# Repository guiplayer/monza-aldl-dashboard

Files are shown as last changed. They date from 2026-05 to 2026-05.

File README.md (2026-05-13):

# Monza ALDL Dashboard

Dashboard embarcado para Chevrolet Monza EFI com comunicação ALDL, display TFT ST7789, sensores auxiliares, logs em cartão SD, upload OTA e mascote animado.

O projeto foi desenvolvido para monitorar dados da ECU Multec 700 via ALDL 8192 baud, exibindo informações em tempo real no display TFT e permitindo diagnósticos, configuração, logs e animações diretamente no ESP32.

---

## 🚗 Veículo alvo

- Chevrolet Monza 1996
- Motor 2.0 EFI gasolina
- ECU Multec 700
- Comunicação ALDL 8192 baud
- Linha ALDL no pino M do conector de diagnóstico

---

## ✨ Principais recursos

- Comunicação ALDL com ECU Multec 700
- Dashboards com dados em tempo real
- Telas individuais de sensores
- Diagnóstico ALDL
- Leitura de códigos de falha da ECU
- Comando para limpar erros da ECU
- Status de SD, I2C, BME280, MPU6050 e alimentação
- Configuração de brilho
- Configuração de buzzer
- Configuração de alertas
- Dashboard inicial configurável
- Upload OTA de firmware via modo AP
- Upload de GIFs via navegador
- GIF de abertura configurável
- Redimensionamento automático de GIFs maiores que a tela
- Logs em CSV no cartão SD
- Limpeza automática de logs antigos
- Tela G-Force usando MPU6050
- Mascote / Monzagotchi com humor baseado nos dados do carro

---

## 🖼️ Galeria do projeto

Imagens reais do painel, dashboards e montagem do projeto.

### Dashboard / interface

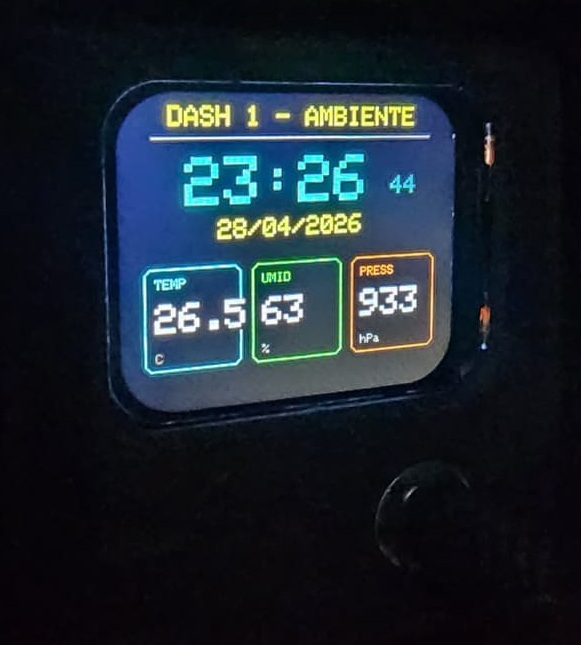
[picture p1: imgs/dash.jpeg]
Dashboard principal


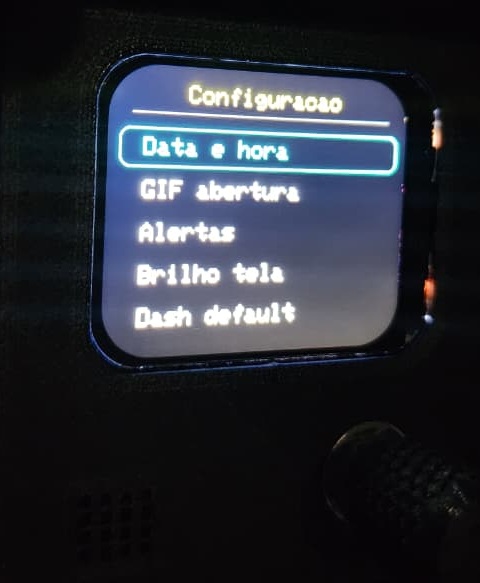
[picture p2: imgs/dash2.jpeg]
Dashboard 2


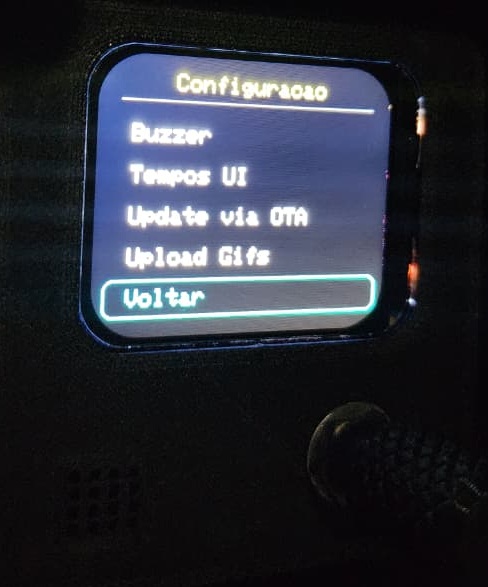
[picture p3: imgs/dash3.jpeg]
Dashboard 3


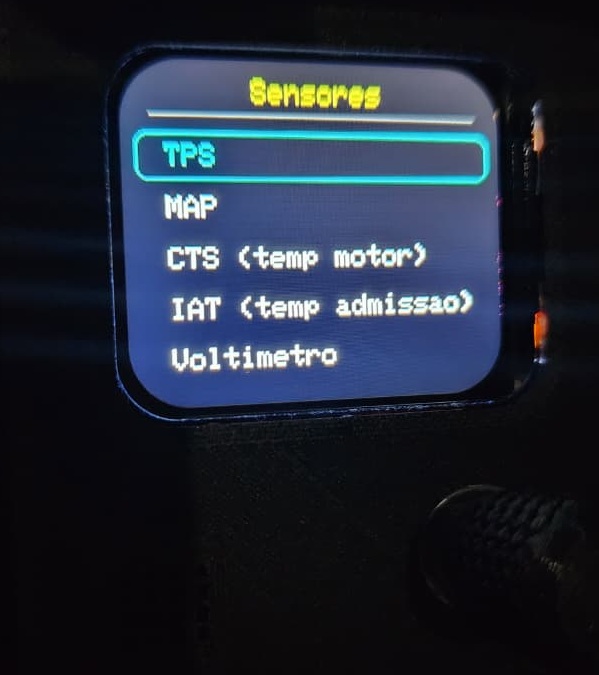
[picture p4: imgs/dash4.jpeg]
Dashboard 4


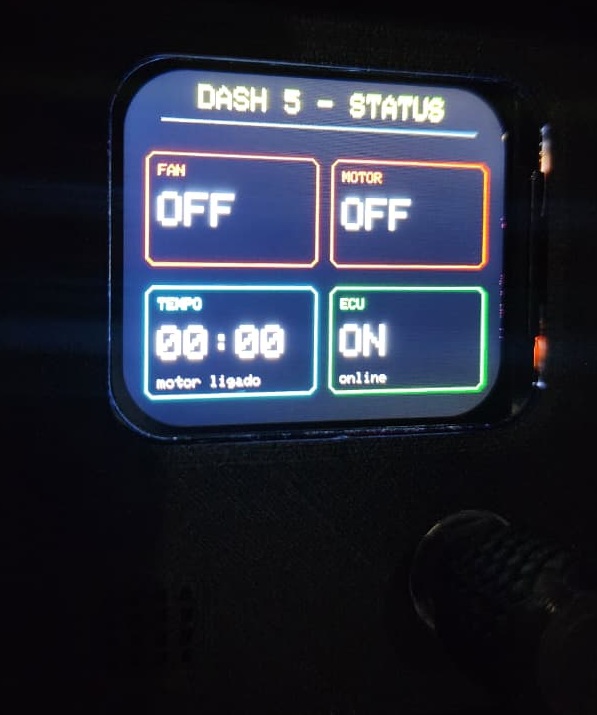
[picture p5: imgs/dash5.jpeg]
Dashboard 5


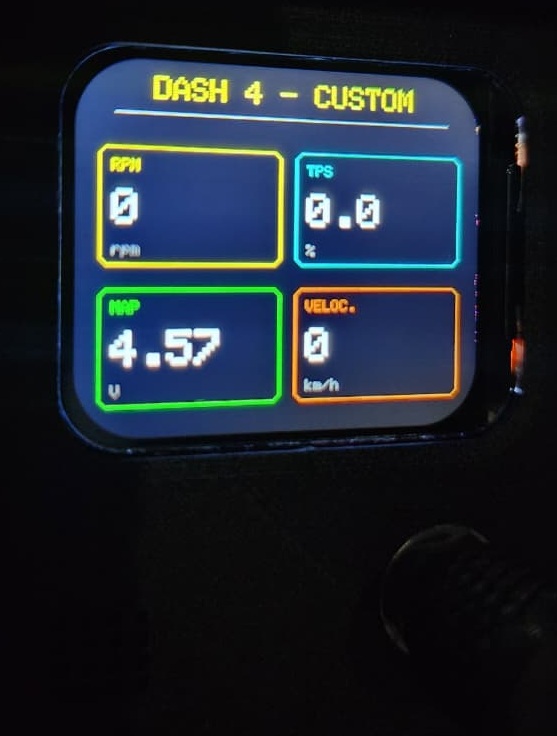
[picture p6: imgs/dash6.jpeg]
Dashboard 6


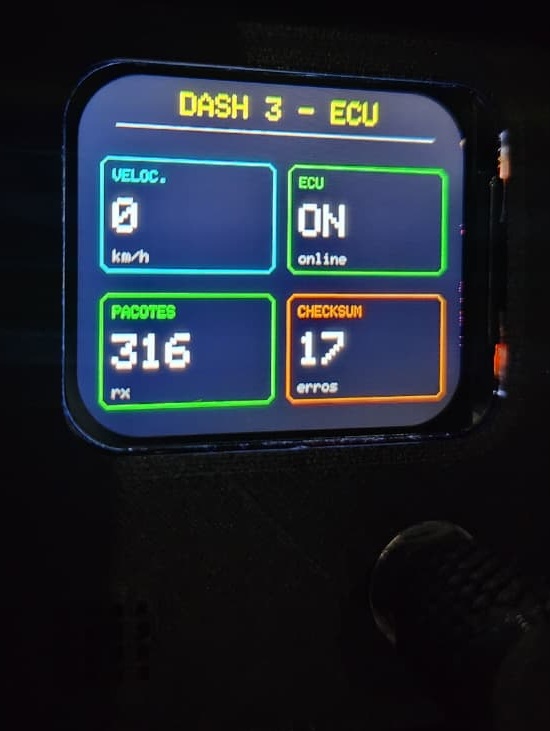
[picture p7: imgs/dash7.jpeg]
Dashboard 7


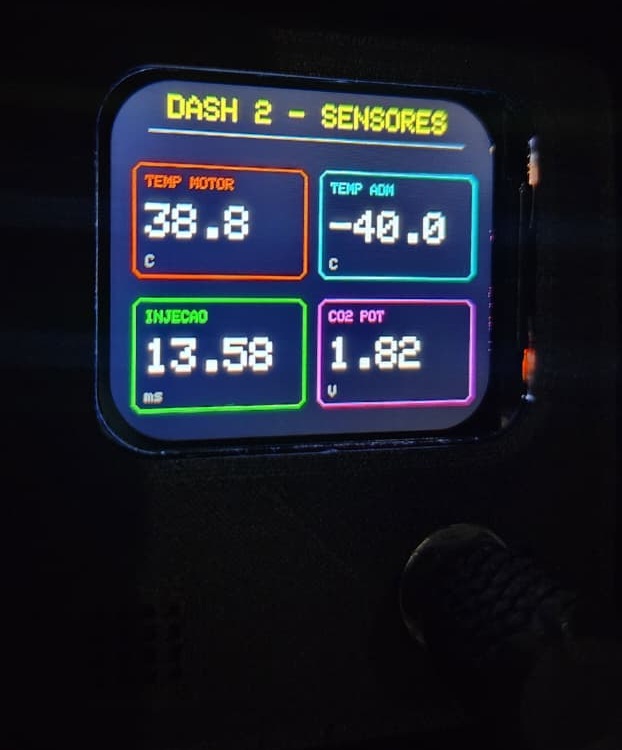
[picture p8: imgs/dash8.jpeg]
Dashboard 8


### GIFs usados no projeto

Os GIFs utilizados no projeto ficam na pasta:

```txt
/gifs/
```

Arquivos adicionados no repositório:

```txt
gifs/abertura.gif
gifs/camera.gif
```

Exemplo de uso:

- `abertura.gif`: GIF de abertura do painel
- `camera.gif`: GIF adicional para testes/animações

### Vídeo de exemplo

Um vídeo demonstrativo também foi adicionado na pasta `imgs`:

```txt
imgs/example.mp4
```

> O vídeo pode ser usado para demonstrar o painel funcionando, menus, dashboards ou animações.

---

## 🧱 Arquivos 3D para impressão

O repositório também possui arquivos STL para impressão 3D da caixa e da frente do projeto.

Arquivos adicionados:

```txt
stl/ALDLMonza_BOX.STL
stl/ALDLMonza_Front.STL
```

### Peças

| Arquivo | Descrição |
|---|---|
| `ALDLMonza_BOX.STL` | Caixa/base do projeto |
| `ALDLMonza_Front.STL` | Frente/moldura do display |

Essas peças podem ser impressas em 3D para montar o painel físico com o ESP32, display ST7789, encoder e demais módulos.

### Sugestões de impressão

- Material: PLA, PETG ou ABS
- Altura de camada: 0.16 mm a 0.28 mm
- Infill: 20% a 40% para uso normal
- Infill maior pode ser usado em suportes ou regiões que precisem de mais resistência
- Conferir a orientação da peça no fatiador antes de imprimir
- Verificar folgas do display, encoder e conectores antes da montagem final

---

## 📁 Estrutura de arquivos de mídia e impressão

Arquivos de mídia e modelos 3D disponíveis no repositório:

```txt
/
├── gifs/
│   ├── abertura.gif
│   └── camera.gif
├── imgs/
│   ├── dash.jpeg
│   ├── dash2.jpeg
│   ├── dash3.jpeg
│   ├── dash4.jpeg
│   ├── dash5.jpeg
│   ├── dash6.jpeg
│   ├── dash7.jpeg
│   ├── dash8.jpeg
│   └── example.mp4
└── stl/
    ├── ALDLMonza_BOX.STL
    └── ALDLMonza_Front.STL
```

---

## 🖥️ Display

O projeto usa um display TFT ST7789 SPI.

Configuração atual:

- Display ST7789
- Resolução usada no projeto: 280 x 240
- Biblioteca: Adafruit ST7789 / Adafruit GFX
- Backlight controlado pelo GPIO 32

---

## 📊 Dashboards

O sistema possui múltiplos dashboards acessíveis pelo menu principal.

### Dashboards atuais

1. **Relógio**
   - Hora
   - Data
   - Temperatura ambiente
   - Umidade
   - Pressão atmosférica

2. **Módulo**
   - ECU ID em hexadecimal
   - ECU ID em decimal
   - Código do módulo
   - Código GM

3. **Motor**
   - RPM
   - TPS
   - MAP
   - Temperatura do motor

4. **Motor 2**
   - Tensão da bateria
   - Velocidade
   - IAC Steps
   - Potenciômetro CO2

5. **Motor 3**
   - RPM
   - TPS
   - MAP
   - Velocidade

6. **Mistura**
   - Avanço de ignição / SPK
   - AFR desejado pela ECU
   - Tempo de injeção
   - Potenciômetro CO2

7. **Status**
   - FAN estimado
   - VMOTOR
   - Tempo de motor ligado
   - Temperatura de admissão

8. **Status ECU**
   - ECU online/offline
   - Pacotes recebidos
   - Erros de checksum
   - Bytes descartados

9. **G-Force**
   - Força lateral
   - Força longitudinal
   - Força vertical
   - G total

---

## 🧪 Sensores e dados ALDL

O projeto lê e exibe diversos dados vindos da ECU via ALDL.

### Telas individuais de sensores

- RPM
- TPS
- MAP
- CTS / temperatura do motor
- IAT / temperatura de admissão
- VBAT / tensão da bateria
- Velocidade
- IAC Steps
- Tempo de injeção
- Potenciômetro CO2
- SPK / avanço de ignição
- AFR desejado pela ECU
- FAN estimado
- VMOTOR
- Tempo de motor ligado

---

## ⚠️ Alertas

O sistema possui alertas configuráveis para:

- Temperatura alta do motor
- Tensão baixa da bateria
- Shift Light por RPM

Quando um alerta é acionado, uma tela de aviso é exibida.

Na tela do mascote, os alertas são representados pelo próprio humor do Monzagotchi.

---

## 🐾 Mascote / Monzagotchi

O projeto possui uma tela de mascote inspirada em Tamagotchi, chamada **Monzagotchi**.

O mascote fica no menu principal, junto com Dashboard, Sensores, Diagnóstico e Configuração.

Menu principal:

```txt
Dashboard
Sensores
Diagnostico
Mascote
Configuracao
```

A tela do mascote também ativa a comunicação ALDL por trás, para que ele reaja aos dados reais do carro.

### Estados do mascote

| Estado | Condição |
|---|---|
| Dormindo | Sem frame válido da ECU / aguardando comunicação |
| Feliz | Dados normais |
| Andando | Velocidade maior que 0 |
| Assustado | RPM acima do limite do Shift Light |
| Triste | ECU offline |
| Doente | Tensão baixa da bateria |
| Quente | Temperatura do motor acima do limite de alerta |

### Frases do mascote

Exemplos de falas usadas na tela:

- `ZzZ... esperando a ECU`
- `Tudo certo no Monza!`
- `Vrum vrum!`
- `EITA RPM!`
- `Cade a ECU?`
- `Bateria fraca :(`
- `To fritando!`

### GIFs do mascote

Os GIFs do mascote ficam na pasta:

```txt
/mascote/
```

Arquivos esperados:

```txt
/mascote/dormindo.gif
/mascote/feliz.gif
/mascote/andando.gif
/mascote/assustado.gif
/mascote/triste.gif
/mascote/doente.gif
/mascote/quente.gif
```

Se algum GIF ainda não foi enviado, a tela mostra um placeholder com o estado atual.

### Upload dos GIFs do mascote

Os GIFs podem ser enviados pelo próprio dashboard usando a tela:

```txt
Configuracao > Upload Gifs
```

O ESP32 cria uma rede Wi-Fi em modo AP. Depois basta acessar o IP informado na tela, normalmente:

```txt
192.168.4.1
```

Na página de upload existe uma área separada para enviar/substituir os GIFs de cada humor do mascote.

---

## 💾 Logs no cartão SD

O projeto possui gravação de logs em CSV no cartão SD.

Os logs são gravados somente quando:

- A opção de logs está ativada
- A tela atual usa dados ALDL
- A ECU está conectada
- Existe frame válido recebido
- O intervalo configurado foi atingido

Os arquivos são salvos na pasta:

```txt
/logs/
```

Formato do nome:

```txt
/logs/aldl_YYYYMMDD_HHMMSS.csv
```

Exemplo:

```txt
/logs/aldl_20260512_213410.csv
```

### Sensores disponíveis para log

É possível escolher quais dados serão gravados:

- RPM
- TPS
- MAP
- CTS / temperatura do motor
- VBAT / tensão da bateria
- Velocidade
- IAC Steps
- Tempo de injeção
- CO2 POT
- SPK / avanço de ignição
- AFR desejado
- FAN estimado
- VMOTOR
- Tempo de motor ligado

### Exemplo de CSV

```csv
millis,data,hora,rpm,tps_percent,map_v,cts_c,vbat_v,velocidade_kmh,iac_steps,injecao_ms,co2_v,spk_graus,afr_desejado,fan,vmotor,tempo_motor_s
123456,12/05/2026,21:34:10,920,0.4,1.28,87.5,13.8,0,34,2.15,1.82,12.3,14.7,OFF,ON,754
```

### Limpeza automática

Quando o cartão SD passa de aproximadamente **90% de uso**, o sistema começa a apagar os logs mais antigos até reduzir o uso para aproximadamente **80%**.

Isso evita que o cartão fique cheio durante o uso.

---

## 📡 Upload OTA

O projeto possui uma tela de atualização OTA via modo AP.

Caminho:

```txt
Configuracao > Update via OTA
```

O ESP32 cria uma rede Wi-Fi própria e permite enviar o firmware pelo navegador.

SSID padrão:

```txt
MonzaDash-OTA
```

Senha padrão:

```txt
12345678
```

IP padrão:

```txt
192.168.4.1
```

---

## 🖼️ Upload de GIFs

O projeto permite enviar GIFs para o cartão SD pelo navegador.

Caminho:

```txt
Configuracao > Upload Gifs
```

A tela de upload permite:

- Enviar GIF de abertura
- Listar GIFs no SD
- Visualizar prévia dos GIFs
- Ver dimensão dos GIFs
- Renomear GIFs
- Deletar GIFs
- Enviar/substituir GIFs do mascote por humor

---

## 🧩 Hardware utilizado

### 🖥️ Display TFT ST7789

Display TFT ST7789 SPI, 8 pinos.

| Display TFT | ESP32 |
|---|---|
| VCC | 3.3V |
| GND | GND |
| SCL | GPIO 18 / SPI Clock |
| SDA | GPIO 23 / SPI MOSI |
| RES | GPIO 4 |
| DC | GPIO 2 |
| CS | GPIO 5 |
| BLK | GPIO 32 ou 3.3V direto |

---

### 🔊 Buzzer passivo

| Buzzer | ESP32 |
|---|---|
| + | GPIO 33 |
| - | GND |

---

### ⏰ RTC DS3231

| DS3231 | ESP32 |
|---|---|
| SDA | GPIO 21 |
| SCL | GPIO 22 |
| VCC | 5V |
| GND | GND |

---

### 🌡️ BME280

| BME280 | ESP32 |
|---|---|
| SDA | GPIO 21 |
| SCL | GPIO 22 |
| VCC | 3.3V |
| GND | GND |

---

### 🧭 GY-521 / MPU6050

| GY-521 / MPU6050 | ESP32 |
|---|---|
| SDA | GPIO 21 |
| SCL | GPIO 22 |
| VCC | 3.3V |
| GND | GND |

---

### 💾 MicroSD

| MicroSD | ESP32 |
|---|---|
| CLK / SCK | GPIO 18 |
| MOSI | GPIO 23 |
| MISO | GPIO 19 |
| CS | GPIO 13 |
| VCC | 3.3V |
| GND | GND |

---

### 🔘 Encoder KY-040

| KY-040 | ESP32 |
|---|---|
| CLK | GPIO 25 |
| DT | GPIO 26 |
| SW | GPIO 27 |
| VCC | 3.3V |
| GND | GND |

---

## 🚗 Ligações com o carro

| Sinal do carro | ESP32 / circuito |
|---|---|
| 5V pós-regulador | VIN do ESP32 |
| GND | GND do ESP32 |
| Iluminação 12V | GPIO 34 |
| ALDL RX | GPIO 16 |
| ALDL TX | GPIO 17 |

> Observação: a linha ALDL do carro não deve ser ligada diretamente ao ESP32 sem o circuito de interface/proteção usado no projeto.

---

## 🔋 Alimentação

A alimentação do projeto é feita a partir dos 12V do carro usando um conversor buck LM2596.

```txt
12V do carro -> LM2596
Saída 5V LM2596 -> VIN do ESP32
Saída 5V LM2596 -> DS3231
3.3V do ESP32 -> Display, BME280, MPU6050, MicroSD e Encoder
GND comum para todos os módulos
```

### Filtro contra ruído no LM2596

Para reduzir ruídos/interferências na alimentação e melhorar a estabilidade da leitura ALDL, foram adicionados capacitores no circuito do LM2596.

Capacitores utilizados:

| Capacitor | Posição sugerida | Função |
|---|---|---|
| 470µF / 25V eletrolítico | Entrada 12V do LM2596 | Ajuda a absorver quedas e oscilações da alimentação do carro |
| 10µF / 16V eletrolítico | Saída 5V do LM2596 | Ajuda a suavizar a saída de 5V |
| 100nF cerâmico | Próximo ao ESP32 e/ou sensores | Ajuda a filtrar ruído de alta frequência |
| 100nF cerâmico | Próximo ao módulo MicroSD | Ajuda na estabilidade durante leitura/gravação no SD |

Ligação recomendada:

```txt
12V carro  ----+---- LM2596 IN+
               |
             470µF
               |
GND carro  ----+---- LM2596 IN-

LM2596 OUT+ ----+---- VIN ESP32
                |
              10µF
                |
GND comum  -----+---- GND ESP32
```

Também é recomendado manter o GND comum entre:

- ESP32
- LM2596
- Display
- Sensores
- MicroSD
- RTC
- Circuito de interface ALDL

---

## 🔌 Barramento I2C

O projeto compartilha o mesmo barramento I2C entre:

- DS3231
- BME280
- MPU6050

Pinos usados:

```txt
SDA -> GPIO 21
SCL -> GPIO 22
```

Endereços comuns:

```txt
DS3231  -> 0x68
BME280  -> 0x76
MPU6050 -> 0x69
```

---

## 🧠 ALDL

Configuração da comunicação:

```txt
Baud rate: 8192
RX: GPIO 16
TX: GPIO 17
```

Comandos usados:

```txt
Shutup request:
F4 56 08 AE

Data stream request:
F4 57 01 00 B4

Clear DTC request:
F4 57 0A 00 AB
```

Frame esperado:

```txt
Header: F4 95 01
Payload: 63 bytes
Checksum: 1 byte
Total: 67 bytes
```

---

## 🧯 Códigos de falha monitorados

A tela de códigos ECU monitora falhas baseadas nos bytes de malfunction word.

Exemplos:

- Erro 12 - Sem pulsos de referência
- Erro 14 - Sensor de temperatura / curto massa
- Erro 15 - Sensor de temperatura / chicote
- Erro 21 - TPS voltagem alta
- Erro 22 - TPS voltagem baixa
- Erro 24 - Sem sinal sensor velocidade
- Erro 32 - Falha sistema EGR
- Erro 33 - MAP sinal alto
- Erro 34 - MAP sinal baixo
- Erro 35 - Atuador IAC
- Erro 42 - Módulo HEI
- Erro 51 - Unidade comando / MEM-CAL
- Erro 54 - Potenciômetro CO2
- Erro 55 - Unidade comando defeito

---

## ⚙️ Configurações salvas no SD

As configurações são salvas no arquivo:

```txt
/config.json
```

Exemplos de dados salvos:

- Brilho dia
- Brilho noite
- GIF de abertura
- Frequências do buzzer
- Modo do buzzer
- Polling ALDL
- Dashboard inicial
- Alertas
- Intervalos de atualização da UI
- Logs SD
- Sensores selecionados para log

---

## 📁 Estrutura sugerida do cartão SD

Estrutura usada no cartão SD instalado no painel:

```txt
/
├── config.json
├── abertura.gif
├── logs/
│   ├── aldl_20260512_213410.csv
│   └── aldl_20260512_214020.csv
└── mascote/
    ├── dormindo.gif
    ├── feliz.gif
    ├── andando.gif
    ├── assustado.gif
    ├── triste.gif
    ├── doente.gif
    └── quente.gif
```

Estrutura dos arquivos versionados no GitHub:

```txt
/
├── gifs/
│   ├── abertura.gif
│   └── camera.gif
├── imgs/
│   ├── dash.jpeg
│   ├── dash2.jpeg
│   ├── dash3.jpeg
│   ├── dash4.jpeg
│   ├── dash5.jpeg
│   ├── dash6.jpeg
│   ├── dash7.jpeg
│   ├── dash8.jpeg
│   └── example.mp4
└── stl/
    ├── ALDLMonza_BOX.STL
    └── ALDLMonza_Front.STL
```

---

## 🛠️ Bibliotecas usadas

- Wire
- SPI
- SD
- ArduinoJson
- AnimatedGIF
- Adafruit GFX
- Adafruit ST7789
- Adafruit BME280
- Adafruit MPU6050
- Adafruit Sensor
- RTClib
- WiFi
- WebServer
- Update
- vector

---

## 📌 Observações importantes

- A linha ALDL precisa de circuito de interface/proteção.
- O ESP32 trabalha em 3.3V.
- Não ligar sinais automotivos de 12V diretamente no ESP32.
- Usar GND comum entre todos os módulos.
- O cartão SD deve estar formatado corretamente.
- GIFs muito grandes podem afetar desempenho.
- Para melhor desempenho, prefira GIFs pequenos e próximos da resolução usada na tela.
- O AFR exibido é o AFR desejado/calculado pela ECU, não leitura real de wideband.
- No Monza EFI sem sonda, alguns dados podem ser fixos ou estimados dependendo da ECU.

---

## 🧪 Status atual

O projeto está em desenvolvimento e testes reais no carro.

Funcionalidades já implementadas:

- Leitura ALDL
- Dashboards
- Telas de sensores
- Logs SD
- Upload de GIFs
- Mascote por humor
- OTA via AP
- G-Force
- Alertas
- Configurações persistentes no SD

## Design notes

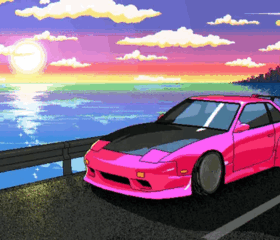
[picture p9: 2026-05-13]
gifs/abertura.gif

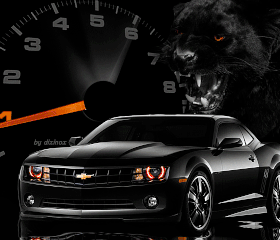
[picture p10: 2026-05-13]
gifs/camaro.gif

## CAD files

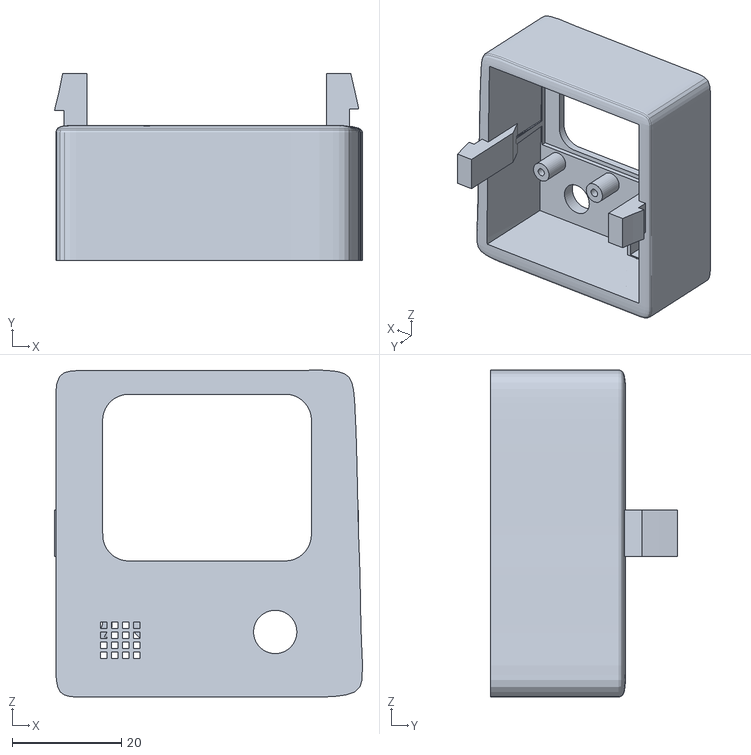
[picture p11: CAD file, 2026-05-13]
stl/ALDLMonza_Front.STL
56.5 x 34.4 x 60.0

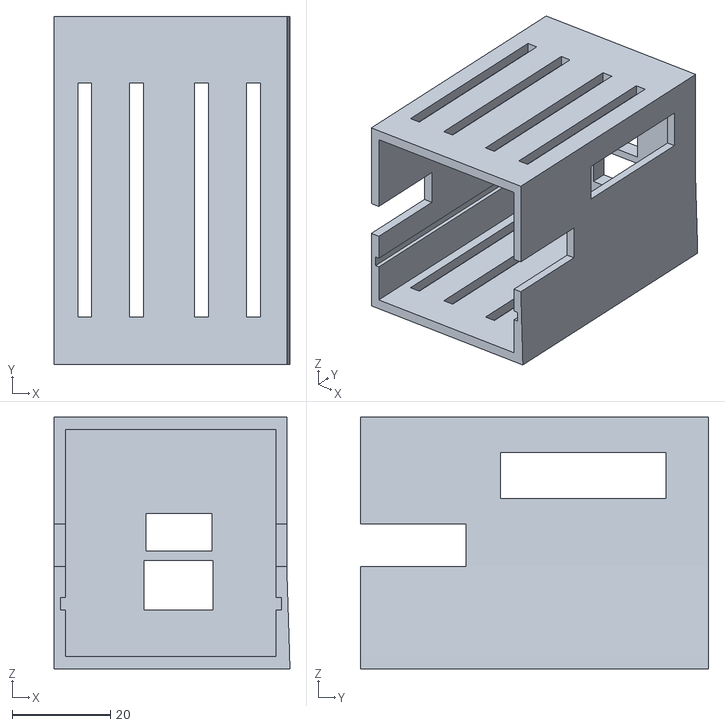
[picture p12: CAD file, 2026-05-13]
stl/ALDLMonza_Box.STL
48.1 x 71.1 x 51.4

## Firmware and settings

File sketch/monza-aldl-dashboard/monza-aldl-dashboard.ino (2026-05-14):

#include <Wire.h>
#include <SPI.h>
#include <SD.h>
#include <ArduinoJson.h>
#include "icones.h"
#include <AnimatedGIF.h>
#include <Adafruit_GFX.h>
#include <Adafruit_ST7789.h>
#include <Adafruit_BME280.h>
#include <Adafruit_MPU6050.h>
#include <Adafruit_Sensor.h>
#include <RTClib.h>
#include <vector>
#include <WiFi.h>
#include <WebServer.h>
#include <Update.h>

// =======================
// CORES
// =======================
#define ST77XX_GREY 0x8410
#ifndef ST77XX_ORANGE
#define ST77XX_ORANGE 0xFD20
#endif
#ifndef ST77XX_MAGENTA
#define ST77XX_MAGENTA 0xF81F
#endif

// =======================
// PINOS (Configuração Original)
// =======================
#define TFT_CS     5
#define TFT_DC     2
#define TFT_RST    4
#define TFT_BLK    32
#define SPI_MOSI   23
#define SPI_CLK    18
#define SD_CS      13
#define SDA_PIN    21
#define SCL_PIN    22
#define ENC_CLK    25
#define ENC_DT     26
#define ENC_SW     27
#define PIN_BUZZER 33
#define PIN_ILUMINACAO  34
#define PIN_SHIFT_LIGHT   35
#define RX2 16
#define TX2 17

// =======================
// CANAIS
// =======================
#define CANAL_BRILHO 0
#define CANAL_BUZZER 2

// =======================
// IDENTIFICADORES DE TELAS (IDs)
// =======================
#define TELA_DASHBOARD        1
#define TELA_AJUSTAR_HORA     2
#define TELA_ALDL             3
#define TELA_TESTE_I2C        4
#define TELA_TESTE_ELET       5
#define TELA_BME              6
#define TELA_MPU              7
#define TELA_STATUS_SD        8
#define TELA_TESTE_BUZZER     9
#define TELA_TESTE_DISPLAY    10
#define TELA_AJUSTE_BRILHO    11
#define TELA_SELECIONAR_GIF   12
#define TELA_CONFIG_BUZZER    13
#define TELA_OTA              14
#define TELA_TPS              15
#define TELA_MAP              16
#define TELA_CTS              17
#define TELA_IAT              18
#define TELA_VOLT             19
#define TELA_RPM              20
#define TELA_TEMPO_INJECAO    21
#define TELA_CO2              22
#define TELA_CODIGOS_ECU      23
#define TELA_LIMPAR_ECU       24
#define TELA_ALERTAS          25
#define TELA_DASH_DEFAULT     26
#define TELA_UPLOAD_GIFS      27
#define TELA_TEMPOS_UI        28
#define TELA_VELOCIDADE       29
#define TELA_IAC              30
#define TELA_SPK              31
#define TELA_AFR              32
#define TELA_FAN              33
#define TELA_VMOTOR           34
#define TELA_TEMPO_MOTOR      35
#define TELA_LOGS_SD          36
#define TELA_MASCOTE          37

// =======================
// OBJETOS
// =======================
Adafruit_ST7789 tft = Adafruit_ST7789(TFT_CS, TFT_DC, TFT_RST);
Adafruit_BME280 bme;
Adafruit_MPU6050 mpu;
RTC_DS3231 rtc;

File gifFile;
AnimatedGIF gif;

// =======================
// OTA AP MODE
// =======================
WebServer otaServer(80);
bool otaAtivo = false;
String otaSSID = "MonzaDash-OTA";
String otaSenha = "12345678";
String otaIP = "";
String otaStatusMsg = "Aguardando upload";
int otaPercent = 0;
bool otaUploadEmAndamento = false;
bool otaReiniciarPendente = false;
unsigned long otaReiniciarEm = 0;

// =======================
// UPLOAD GIFS VIA AP
// =======================
bool gifUploadAtivo = false;
bool gifUploadErro = false;
bool gifUploadEmAndamento = false;
String gifUploadStatusMsg = "Aguardando upload";
String gifUploadNomeArquivo = "";
int gifUploadPercent = 0;
File gifUploadFile;

// =======================
// SEUS MENUS (MANTIDOS ORIGINAIS)
// =======================
struct Menu {
  const char* titulo;
  const char** itens;
  int total;
  Menu* parent;
};

const char* menuPrincipalItens[] = {"Dashboard","Sensores","Diagnostico","Mascote","Configuracao"};
const char* submenuSensores[] = {"RPM","TPS","MAP","CTS Temp Motor","IAT Temp Adm","VBAT","Velocidade","IAC Steps","Tempo Injecao","CO2 POT","SPK Avanco","AFR Desejado","FAN","VMOTOR","Tempo Motor","Voltar"};
const char* submenuDiagnostico[] = {"Status ALDL","Codigos ECU","Limpar erros ECU","Status MPU","Status BME","Status I2C","Status Iluminacao","SD Card","Teste Buzzer","Teste Display","Voltar"};
const char* submenuConfig[] = {"Data e hora","GIF abertura","Alertas","Brilho tela","Dash default","Buzzer","Tempos UI","Logs SD","Update via OTA","Upload Gifs","Voltar"};

Menu menuPrincipal = { "Menu Principal", menuPrincipalItens, 5, nullptr };
Menu menuSensores = { "Sensores", submenuSensores, 16, &menuPrincipal };
Menu menuDiagnostico = { "Diagnostico", submenuDiagnostico, 11, &menuPrincipal };
Menu menuConfig = { "Configuracao", submenuConfig, 11, &menuPrincipal };

Menu* menuAtual = &menuPrincipal;
int menuIndex = 0;

// =======================
// ESTADO DO SISTEMA
// =======================
enum EstadoUI { MENU_UI, TELA_UI };
EstadoUI estadoUI = MENU_UI;
int telaAtiva = 0;
int lastCLK = HIGH;
unsigned long ultimoUpdate = 0;
unsigned long intervaloUpdateMs = 250;
static uint16_t lineBuffer[280];
uint16_t gifOrigW = 280;
uint16_t gifOrigH = 240;
uint16_t gifDrawW = 280;
uint16_t gifDrawH = 240;
int16_t gifOffsetX = 0;
int16_t gifOffsetY = 0;
bool gifEscalarParaTela = false;

int leituraIluminacao = 0;
int ajustePasso = 0;

int movimentoEncoder = 0;
bool cliqueDetectado = false;

int modoBuzzer = 1; // 0: Off, 1: Simples, 2: Duplo

unsigned long bytesEnviados = 0;
unsigned long bytesRecebidosTotal = 0;
unsigned long ecosDescartados = 0;
unsigned long contTX = 0;
unsigned long contEco = 0;
unsigned long contErroSync = 0;
unsigned long bytesLixoDescartados = 0;
uint8_t ultimoHeader = 0x00;
uint8_t ultimoID2 = 0x00;

// Variáveis que serão salvas
int brilhoDia = 255;
int brilhoNoite = 255;
String gifAbertura = "abertura.gif";
unsigned long gifAberturaTempoMaxMs = 6000;
int freqEncoder = 1200;
int freqClique = 2000;
int freqSucesso = 2500;
int freqErro = 800;

// Variáveis da Multec 700
int valorRPM = 0;
float valorTPS = 0;
float tempMotor = 0;
float valorMAP = 0;
float voltagem = 0;
float voltCO2 = 0;
float valorAvancoIgnicao = 0;
float valorAFR = 0;
float tempoInjecao = 0;
float tempAdmissao = 0;
int velocidade = 0;
int valorIAC = 0;
uint32_t tempoMotorLigado = 0;
int errosChecksum = 0;
unsigned long ultimaMensagemALDL = 0;
int pacotesRecebidos = 0;
bool ecuConectada = false;
uint8_t malf1 = 0;
uint8_t malf2 = 0;
uint8_t malf3 = 0;
uint8_t lccpmw = 0;
float fanEstimadoLimite = 100.0;
float fanEstimadoLigaLimite = 100.0;
float fanEstimadoDesligaLimite = 96.0;
bool fanEstimadoLigada = false;
uint16_t ecuIdRaw = 0;
String ecuModuloCodigo = "";
String ecuModuloNome = "";
String ecuModuloDescricao = "";

// =======================
// LOGS SD
// =======================
const char* LOGS_DIR = "/logs";
const char* MASCOTE_DIR = "/mascote";

bool logsSdAtivo = false;
unsigned long logsSdIntervaloMs = 1000;
unsigned long logsSdUltimaGravacao = 0;
unsigned long logsSdUltimaLimpeza = 0;

bool logsSdSessaoAberta = false;
String logsSdArquivoAtual = "";
File logsSdFile;

bool logRPM = true;
bool logTPS = true;
bool logMAP = true;
bool logCTS = true;
bool logVBAT = true;
bool logVelocidade = true;
bool logIAC = true;
bool logInjecao = true;
bool logCO2 = true;
bool logSPK = true;
bool logAFR = true;
bool logFan = true;
bool logVMotor = true;
bool logTempoMotor = true;

uint64_t logsSdBytesGravadosSessao = 0;
int logsSdLinhasSessao = 0;
String logsSdStatusMsg = "Logs desligados";


// Variaveis Gforce
float gLateral = 0.0f;
float gLongitudinal = 0.0f;
float gVertical = 0.0f;
float gTotal = 0.0f;

float gOffsetX = 0.0f;
float gOffsetY = 0.0f;
float gOffsetZ = 0.0f;

bool gForceCalibrado = false;
unsigned long gForceUltimaLeitura = 0;

// Variaveis Alertas
bool alertaTempMotorAtivo = true;
bool alertaTensaoAtivo = true;
bool alertaShiftLightAtivo = true;

float alertaTempMotorLimite = 105.0;
float alertaTensaoMinima = 11.5;
int alertaShiftLightRPM = 5500;

bool alertaEstavaAtivo = false;
bool forcarRedesenhoTela = false;

// Variaveis Dash
int dashAtual = 0;
int dashInicialDefault = -1; // -1 = nenhum
const int totalDashboards = 9;

// Cache visual dos dashboards para evitar flicker
struct CardDashCache {
  bool usado;
  int x;
  int y;
  int w;
  int h;
  char titulo[24];
  char valor[24];
  char unidade[18];
  uint16_t cor;
};

CardDashCache cacheCardsDash[8];

bool cacheHeaderDashDesenhado = false;
char cacheHeaderDashTitulo[40] = "";
int cacheHeaderDashAtual = -1;

// Nome arquivo json
const char* configFile = "/config.json";


// Variaveis mascote
enum EstadoMascote {
  MASCOTE_DORMINDO,
  MASCOTE_FELIZ,
  MASCOTE_ANDANDO,
  MASCOTE_ASSUSTADO,
  MASCOTE_TRISTE,
  MASCOTE_DOENTE,
  MASCOTE_QUENTE
};

EstadoMascote estadoMascoteAtual = MASCOTE_DORMINDO;
EstadoMascote ultimoEstadoMascote = MASCOTE_DORMINDO;

String gifMascoteDormindo = "/mascote/dormindo.gif";
String gifMascoteFeliz = "/mascote/feliz.gif";
String gifMascoteAndando = "/mascote/andando.gif";
String gifMascoteAssustado = "/mascote/assustado.gif";
String gifMascoteTriste = "/mascote/triste.gif";
String gifMascoteDoente = "/mascote/doente.gif";
String gifMascoteQuente = "/mascote/quente.gif";

bool mascoteGifAberto = false;
bool mascoteGifExiste = false;
String mascoteGifAtual = "";
EstadoMascote mascoteEstadoGifAberto = MASCOTE_DORMINDO;

const int MASCOTE_GIF_X = 40;
const int MASCOTE_GIF_Y = 48;
const int MASCOTE_GIF_W = 200;
const int MASCOTE_GIF_H = 125;

// ======================================================
// ALDL MULTEC 700
// ======================================================
static const uint32_t ALDL_BAUD_RATE = 8192;
unsigned long aldlPollingMs = 100;
static const unsigned long ALDL_DELAY_SHUTUP_MS = 500;
static const unsigned long ALDL_TIMEOUT_CONECTADA_MS = 2000;

static const uint8_t ALDL_REQ_SHUTUP[] = { 0xF4, 0x56, 0x08, 0xAE };
static const uint8_t ALDL_REQ_STREAM[] = { 0xF4, 0x57, 0x01, 0x00, 0xB4 };
static const uint8_t ALDL_REQ_CLEAR_DTC[] = { 0xF4, 0x57, 0x0A, 0x00, 0xAB };

static const uint8_t ALDL_FRAME_START[] = { 0xF4, 0x95, 0x01 };
static const size_t ALDL_HEADER_LEN = 3;
static const size_t ALDL_PAYLOAD_LEN = 63;
static const size_t ALDL_CHECKSUM_LEN = 1;
static const size_t ALDL_FRAME_LEN = ALDL_HEADER_LEN + ALDL_PAYLOAD_LEN + ALDL_CHECKSUM_LEN;

bool aldlAtivo = false;
bool aldlShutupEnviado = false;
bool aldlBufferLimpoAposShutup = false;
bool aldlPrimeiroFrameOk = false;

unsigned long aldlMillisInicioSessao = 0;
unsigned long aldlUltimoPolling = 0;
unsigned long dashboardUiUpdateMs = 300;
unsigned long aldlUiUpdateMs = 180;

uint8_t aldlUltimoTx[8];
size_t aldlUltimoTxLen = 0;

uint8_t aldlRxBuffer[512];
size_t aldlRxLen = 0;

uint8_t aldlUltimoFrame[ALDL_FRAME_LEN];
bool aldlTemFrameValido = false;

// =======================
// PROTÓTIPOS
// =======================
void desenharMenu();
void lerEncoder();
void selecionarItemMenu();
void atualizarTela();
void atualizarDashboard();
void desenharDashboardHeader(const char* titulo);
void desenharCardDash(int x, int y, int w, int h, const char* titulo, const char* valor, const char* unidade, uint16_t cor);
void limparCacheDashboard();
int obterSlotCardDash(int x, int y, int w, int h);
void dashboardRelogioBME();
void dashboardALDL1();
void dashboardALDL2();
void dashboardALDL3();
void dashboardALDL4();
void dashboardALDL5();
void dashboardALDL6();
void dashboardALDL7();
void ajustarHora();
void telaStatusI2C();
void telaStatusEletrico();
void telaStatusSD();
void telaStatusALDL();
void telaTesteBuzzer();
void telaTesteDisplay();
void telaAjusteBrilho();
void telaSelecaoGif();
void telaConfigBuzzer();
void telaOTA();
void telaUploadGifs();
void iniciarUploadGifs();
void pararUploadGifs();
void loopUploadGifs();
void configurarRotasUploadGifs();
String sanitizarNomeArquivoGif(String nome);
String htmlEscape(String texto);
String urlEncode(String texto);
bool ehArquivoGifSeguro(String caminho);
bool obterDimensaoGif(String caminho, uint16_t &largura, uint16_t &altura);
String montarHtmlListaGifs();
void telaSensorCO2();
void telaTemposUI();
void desenharLinhaTempoUI(int y, const char* nome, unsigned long valor, bool selecionado, bool editando);
void telaCodigosECU();
void telaLimparErrosECU();
void formatarTempoMotor(char* buffer, size_t tamanho, uint32_t segundos);
std::vector<String> obterFalhasAtivas();
void salvarConfiguracoes();
void carregarConfiguracoes();
void desenharAlertaTela(const char* titulo, const char* mensagem, uint16_t corFundo);
void * GIFOpenFile(const char *fname, int32_t *pSize);
void GIFCloseFile(void *pHandle);
int32_t GIFReadFile(GIFFILE *pFile, uint8_t *pBuf, int32_t iLen);
int32_t GIFSeekFile(GIFFILE *pFile, int32_t iPosition);
void GIFDraw(GIFDRAW *pDraw);
void rodarGifAbertura(String nomeArquivo);
void telaStatusBME();
void telaStatusMPU();
void telaAlerta();
void telaDashDefault();
bool verificarAlertas();
bool atualizarFanEstimado();
void ajustarBacklight();
void beep(int freq);
void desenharLinhaAlertaInt(int y, const char* nome, int valor, const char* unidade, bool selecionado, bool editando);
void desenharLinhaAlertaTexto(int y, const char* nome, const char* valor, bool selecionado, bool ativo);
void desenharLinhaAlertaValor(int y, const char* nome, float valor, const char* unidade, bool selecionado, bool editando);
void dashboardGForce();
void atualizarGForce();
void calibrarGForce();
float normalizarZeroGForce(float valor);
void telaLogsSD();
void loopLogsSD();
void iniciarSessaoLogSD();
void fecharLogSD();
void escreverCabecalhoLogSD(File &file);
void escreverLinhaLogSD(File &file);
bool garantirPastaLogs();
void limparLogsSeNecessario();
bool apagarLogMaisAntigo();
uint64_t calcularTamanhoPasta(const char* caminho);
int contarArquivosLogs();
String formatarBytesSD(uint64_t bytes);
void apagarTodosLogs();
void desenharLinhaLogOpcao(int y, const char* nome, bool valor, bool selecionado);
void desenharLinhaLogValor(int y, const char* nome, unsigned long valor, const char* unidade, bool selecionado);
void desenharLinhaLogTexto(int y, const char* nome, const char* valor, bool selecionado);
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
void loop() {
  if (estadoUI == TELA_UI && telaEhSensorALDL(telaAtiva)) {
    if (!aldlAtivo) {
      iniciarALDL();
    }
    loopALDL();
  } else {
    if (aldlAtivo) {
      pararALDL();
    }
  }

  if (logsSdAtivo && estadoUI == TELA_UI && telaEhSensorALDL(telaAtiva)) {
    loopLogsSD();
  } else {
    if (logsSdSessaoAberta) {
      fecharLogSD();
    }
  }

  if (estadoUI == TELA_UI && telaAtiva == TELA_OTA) {
    loopOTA();
  }

  if (estadoUI == TELA_UI && telaAtiva == TELA_UPLOAD_GIFS) {
    loopUploadGifs();
  }

  ajustarBacklight();
  lerEncoder();

  bool alertaAtivo = verificarAlertas();

  if (!alertaAtivo && alertaEstavaAtivo) {
    alertaEstavaAtivo = false;
    forcarRedesenhoTela = true;
    tft.fillScreen(ST77XX_BLACK);
    ultimoUpdate = 0;
  }

  if (alertaAtivo) {
    alertaEstavaAtivo = true;
  }

  if (!alertaAtivo && estadoUI == TELA_UI) {
    unsigned long intervaloAtual = intervaloUpdateMs;

    if (telaEhSensorALDL(telaAtiva)) intervaloAtual = aldlUiUpdateMs;
    if (telaAtiva == TELA_DASHBOARD) intervaloAtual = dashboardUiUpdateMs;
    if (telaAtiva == TELA_OTA || telaAtiva == TELA_UPLOAD_GIFS) intervaloAtual = 250;    

    if (millis() - ultimoUpdate >= intervaloAtual || movimentoEncoder != 0 || forcarRedesenhoTela) {
      ultimoUpdate = millis();

      bool estavaForcandoRedesenho = forcarRedesenhoTela;

      atualizarTela();

      if (estavaForcandoRedesenho) {
        forcarRedesenhoTela = false;
      }
    }
  }

  delay(1);
}

bool verificarAlertas() {
  if (estadoUI != TELA_UI) return false;
  if (!telaEhSensorALDL(telaAtiva)) return false;
  if (telaAtiva == TELA_MASCOTE) return false;

  // Nao dispara alerta antes do primeiro frame valido
  if (!aldlPrimeiroFrameOk) return false;
  if (!aldlTemFrameValido) return false;
  if (pacotesRecebidos <= 0) return false;

  // Garante que a ECU ainda esta viva
  ecuConectada = (millis() - ultimaMensagemALDL < ALDL_TIMEOUT_CONECTADA_MS);
  if (!ecuConectada) return false;

  if (alertaTempMotorAtivo && tempMotor >= alertaTempMotorLimite) {
    desenharAlertaTela("TEMP MOTOR", "ALTA", ST77XX_RED);
    return true;
  }

  if (alertaTensaoAtivo && voltagem > 0 && voltagem <= alertaTensaoMinima) {
    desenharAlertaTela("TENSAO", "BAIXA", ST77XX_ORANGE);
    return true;
  }

  if (alertaShiftLightAtivo && valorRPM >= alertaShiftLightRPM) {
    desenharAlertaTela("SHIFT", "TROCAR MARCHA", ST77XX_YELLOW);
    return true;
  }

  return false;
}

void prepararEscalaGif(String nomeArquivo) {
  gifOrigW = 280;
  gifOrigH = 240;
  gifDrawW = 280;
  gifDrawH = 240;
  gifOffsetX = 0;
  gifOffsetY = 0;
  gifEscalarParaTela = false;

  uint16_t largura = 0;
  uint16_t altura = 0;

  if (!obterDimensaoGif(nomeArquivo, largura, altura)) {
    return;
  }

  if (largura == 0 || altura == 0) {
    return;
  }

  gifOrigW = largura;
  gifOrigH = altura;

  if (largura <= 280 && altura <= 240) {
    gifDrawW = largura;
    gifDrawH = altura;
    gifOffsetX = 0;
    gifOffsetY = 0;
    gifEscalarParaTela = false;
    return;
  }

  float escalaX = 280.0f / (float)largura;
  float escalaY = 240.0f / (float)altura;
  float escala = escalaX < escalaY ? escalaX : escalaY;

  gifDrawW = (uint16_t)((float)largura * escala);
  gifDrawH = (uint16_t)((float)altura * escala);

  if (gifDrawW < 1) gifDrawW = 1;
  if (gifDrawH < 1) gifDrawH = 1;
  if (gifDrawW > 280) gifDrawW = 280;
  if (gifDrawH > 240) gifDrawH = 240;

  gifOffsetX = (280 - gifDrawW) / 2;
  gifOffsetY = (240 - gifDrawH) / 2;

  gifEscalarParaTela = true;
}

void desenharAlertaTela(const char* titulo, const char* mensagem, uint16_t corFundo) {
  static unsigned long ultimoDesenho = 0;
  static char ultimoTitulo[24] = "";
  static char ultimoMensagem[32] = "";
  static uint16_t ultimaCor = 0;
  static bool alertaDesenhado = false;


  bool mudouAlerta =
    strcmp(ultimoTitulo, titulo) != 0 ||
    strcmp(ultimoMensagem, mensagem) != 0 ||
    ultimaCor != corFundo;

  if (mudouAlerta) {
    strncpy(ultimoTitulo, titulo, sizeof(ultimoTitulo) - 1);
    ultimoTitulo[sizeof(ultimoTitulo) - 1] = '\0';

    strncpy(ultimoMensagem, mensagem, sizeof(ultimoMensagem) - 1);
    ultimoMensagem[sizeof(ultimoMensagem) - 1] = '\0';

    ultimaCor = corFundo;

    alertaDesenhado = false;
  }

  // Evita redesenhar sem necessidade
  if (alertaDesenhado && millis() - ultimoDesenho < 300) {
    return;
  }

  ultimoDesenho = millis();
  alertaDesenhado = true;

  uint16_t corTexto = ST77XX_WHITE;

  if (corFundo == ST77XX_YELLOW || corFundo == ST77XX_ORANGE || corFundo == ST77XX_CYAN) {
    corTexto = ST77XX_BLACK;
  }

  tft.fillScreen(corFundo);
  tft.drawRoundRect(10, 45, 260, 150, 8, corTexto);

  tft.setTextWrap(false);

  tft.setTextSize(3);
  tft.setTextColor(corTexto, corFundo);

  int16_t x1, y1;
  uint16_t w, h;

  tft.getTextBounds(titulo, 0, 0, &x1, &y1, &w, &h);
  tft.setCursor((280 - w) / 2, 75);
  tft.print(titulo);

  tft.setTextSize(2);
  tft.getTextBounds(mensagem, 0, 0, &x1, &y1, &w, &h);
  tft.setCursor((280 - w) / 2, 125);
  tft.print(mensagem);

}

// =======================
// FUNÇÕES DE MENU E ENCODER
// =======================
void desenharMenu() {
  limparCacheDashboard();
  tft.fillScreen(ST77XX_BLACK);

  int screenW = tft.width();
  int screenH = tft.height();
  int itemHeight = 35;
  int visibleItems = (screenH - 55) / itemHeight;
  int scrollOffset = (menuIndex >= visibleItems) ? menuIndex - visibleItems + 1 : 0;

  tft.setTextSize(2);
  int16_t x1, y1; uint16_t w, h_titulo;
  tft.getTextBounds(menuAtual->titulo, 0, 0, &x1, &y1, &w, &h_titulo);
  tft.setCursor((screenW - w) / 2, 15);
  tft.setTextColor(ST77XX_YELLOW, ST77XX_BLACK);
  tft.print(menuAtual->titulo);

  tft.drawFastHLine(20, 38, screenW - 40, ST77XX_GREY);

  for (int i = 0; i < visibleItems; i++) {
    int itemIndex = i + scrollOffset;
    if (itemIndex >= menuAtual->total) break;

    int y = 55 + i * itemHeight;
    uint16_t corItem = (itemIndex == menuIndex) ? ST77XX_CYAN : ST77XX_WHITE;

    if (itemIndex == menuIndex) {
      tft.drawRoundRect(10, y - 4, screenW - 20, 32, 8, ST77XX_CYAN);
    }

    if (menuAtual == &menuPrincipal) {
      const unsigned char* bitmap = nullptr;
      switch(itemIndex) {
        case 0: bitmap = icone_dash; break;
        case 1: bitmap = icone_sensor; break;
        case 2: bitmap = icone_engine; break;
        case 3: bitmap = icone_mascote; break;
        case 4: bitmap = icone_config; break;
      }

      if (bitmap != nullptr) {
        tft.drawBitmap(20, y, bitmap, 24, 24, corItem);
      }

      tft.setCursor(55, y + 4);
    } else {
      tft.setCursor(30, y + 4);
    }

    tft.setTextColor(corItem, ST77XX_BLACK);
    tft.print(menuAtual->itens[itemIndex]);
  }
}

void lerEncoder() {
  movimentoEncoder = 0;
  cliqueDetectado = false;

  if (digitalRead(ENC_SW) == LOW) {
    delay(50);
    cliqueDetectado = true;

    if (estadoUI == TELA_UI &&
      !telaEhSensorALDL(telaAtiva) &&
      telaAtiva != TELA_AJUSTAR_HORA &&
      telaAtiva != TELA_AJUSTE_BRILHO &&
      telaAtiva != TELA_CONFIG_BUZZER &&
      telaAtiva != TELA_SELECIONAR_GIF &&
      telaAtiva != TELA_OTA &&
      telaAtiva != TELA_MPU &&
      telaAtiva != TELA_BME &&
      telaAtiva != TELA_TESTE_I2C &&
      telaAtiva != TELA_TESTE_ELET &&
      telaAtiva != TELA_ALERTAS &&
      telaAtiva != TELA_TESTE_DISPLAY &&
      telaAtiva != TELA_UPLOAD_GIFS &&
      telaAtiva != TELA_TEMPOS_UI &&
      telaAtiva != TELA_LOGS_SD &&
      telaAtiva != TELA_DASH_DEFAULT) {

      estadoUI = MENU_UI;
      desenharMenu();
      beep(freqClique);
      cliqueDetectado = false;
    }
    else if (estadoUI == MENU_UI) {
      selecionarItemMenu();
      cliqueDetectado = false;
    }

    while (digitalRead(ENC_SW) == LOW);
  }

  int clk = digitalRead(ENC_CLK);
  if (clk != lastCLK) {
    if (clk == LOW) {
      movimentoEncoder = (digitalRead(ENC_DT) != clk) ? 1 : -1;
      if (estadoUI == MENU_UI) {
        menuIndex = (menuIndex + movimentoEncoder + menuAtual->total) % menuAtual->total;
        desenharMenu();
        beep(1200);
      }
    }
    lastCLK = clk;
  }
}
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

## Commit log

2026-04-24 Alterações diretorio sketch e modificações sensores (#1)
2026-04-24 Inserido yml de releases (#3)
2026-04-24 Alteração de bibliotecas de compilação (#5)
2026-04-27 Alteracaobmempu (#6)
    * Alteração de bibliotecas de compilação
    * Alterações nova bme e mpu
    * Inserção dashboards e alertas
    ---------
2026-04-27 Correcaobugs (#8)
    * Correção novas telas
    * Correção bugs telas
    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
    [monza-aldl-dashboard.ino]
2026-04-27 Correção de flags invertidas (#9)
2026-04-29 Correção telas de alertas (#13)
2026-05-13 Correção diversas e melhorias de codigo (#17)
2026-05-13 Inserção de gifs e imagens do projeto (#18)
    [ALDLMonza_Box.STL, ALDLMonza_Front.STL]
2026-05-14 Alteracoesgifeimg (#19)
    * Inserção de gifs e imagens do projeto
    * Alterações img e gifs
2026-10-15 App Android para monitorar o ALDL via Wi-Fi (#20)
    - Firmware: nova tela Configuracao > App Celular; AP Wi-Fi compartilhado
    entre app, OTA e upload de GIFs; telemetria JSON via TCP na porta 3333;
    ECU lida em qualquer tela enquanto o app estiver conectado; comando CLR
    para limpar erros da ECU.
    - App Flutter (app/): painel com RPM e sensores, alertas com os limites do
    painel, codigos de falha e status da ECU.
    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
